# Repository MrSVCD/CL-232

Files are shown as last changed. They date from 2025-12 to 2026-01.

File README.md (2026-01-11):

# CL-232

## In progress - Ver 0.4

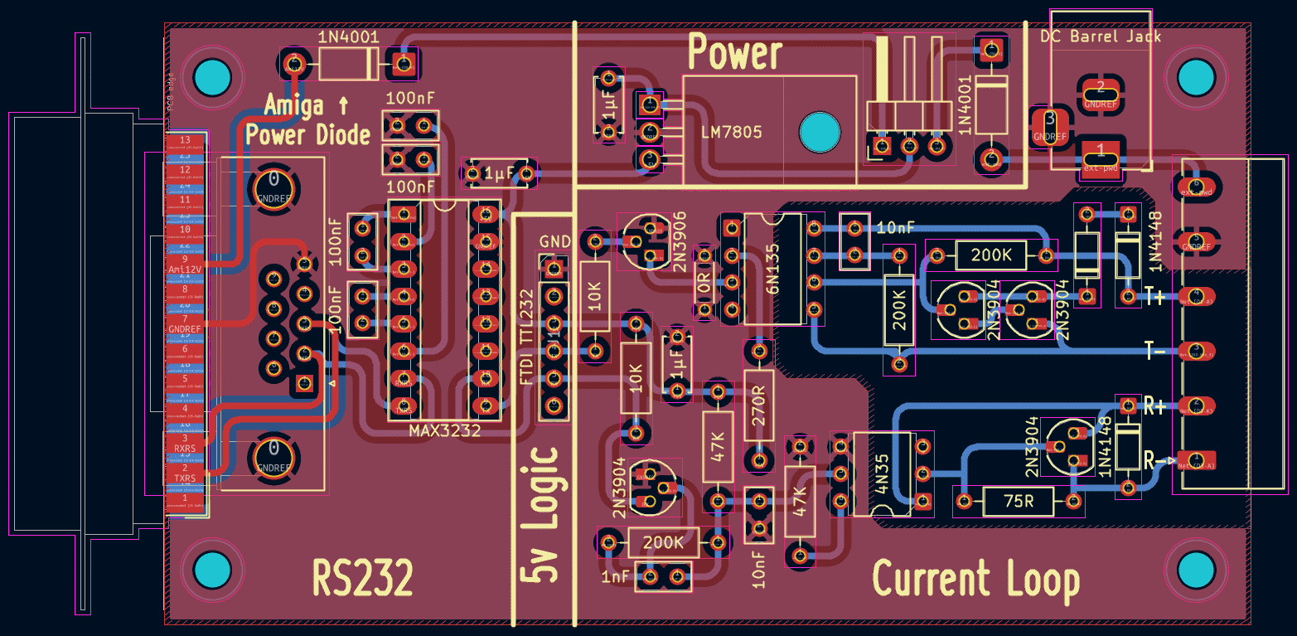
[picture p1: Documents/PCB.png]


This is a current loop to 5V Logic/RS232 adapter for using old old hardware or serial communication over a long distance, old old school style.

The adapter is based on B&B electronics [design](Documents/B&B%20Electronics%20-%20232CL9R.pdf) with some additions sutch as running of a Amiga serial ports power or skipping the whole RS232 to 5V Logic converter part and run it of a USB to TTL232 adapter. 

I also changed the 5V Logic <-> RS232 chip to a single MAX3232 which has the added benefit to only need +5v instead of the old design needing +/-12v, this also makes the adapter able to run on USB power. The Current Loop probably needs more than 5v to get any length going but it should be possible to get a short link going with just 5v, all the old documentation I have found uses 12v or more. 

## Current Limiter
In the folder [CurrentLimiter](CurrentLimiter) there is a simple Current Limiter based on a LM317 and a 62Ω resistor. This current limiter works on a loop up to 40 volts.

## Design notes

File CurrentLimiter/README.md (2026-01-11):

# Current Limiter
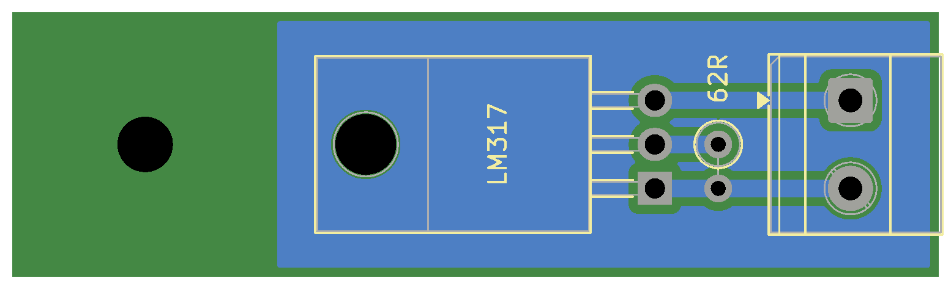
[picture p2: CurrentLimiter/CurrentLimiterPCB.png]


This is a simple PCB that uses a LM317 and a 68Ω resistor to make a 20mA current limiter that adjusts for different voltages (up to 40volts).

The circuit is so simple that a PCB is not really necessary. If you build one without a PCB, remember that the exposed metal on the TO-220 version is connected to voltage out and should be isolated if it needs cooling.

## Resistor value examples:
| Target mA | Exact Ω | Nearest E24 resistor| Resulting mA |
|---:|---:|---:|---:|
| 5 |  256,00 | 270 | 4,74 |
| 10 |  128,00 | 120 | 10,67 |
| 20 | 64,00 | 62 | 20,65 |
| 30 | 42,67 | 43 | 29,77 |
| 40 | 32,00 | 33 | 38,79 |
| 50 | 25,60 | 27 | 47,41 |

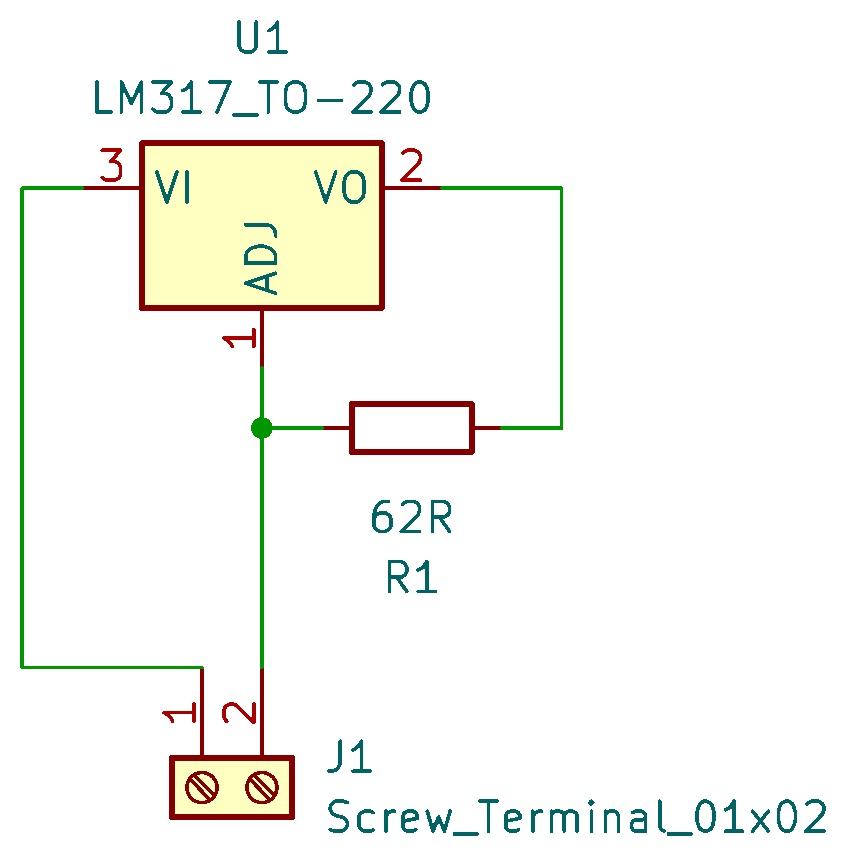
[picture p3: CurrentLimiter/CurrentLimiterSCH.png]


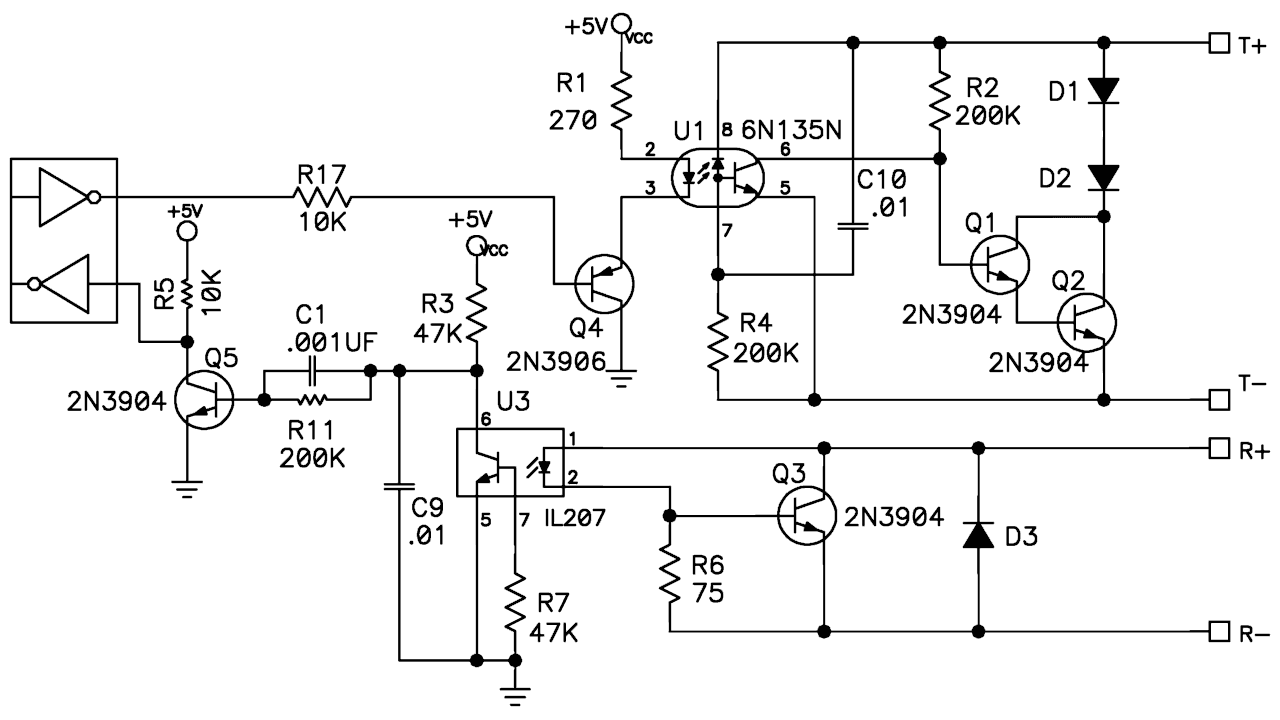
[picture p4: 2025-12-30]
Documents/B&B Electronics - 232CL9R - Schematic.png

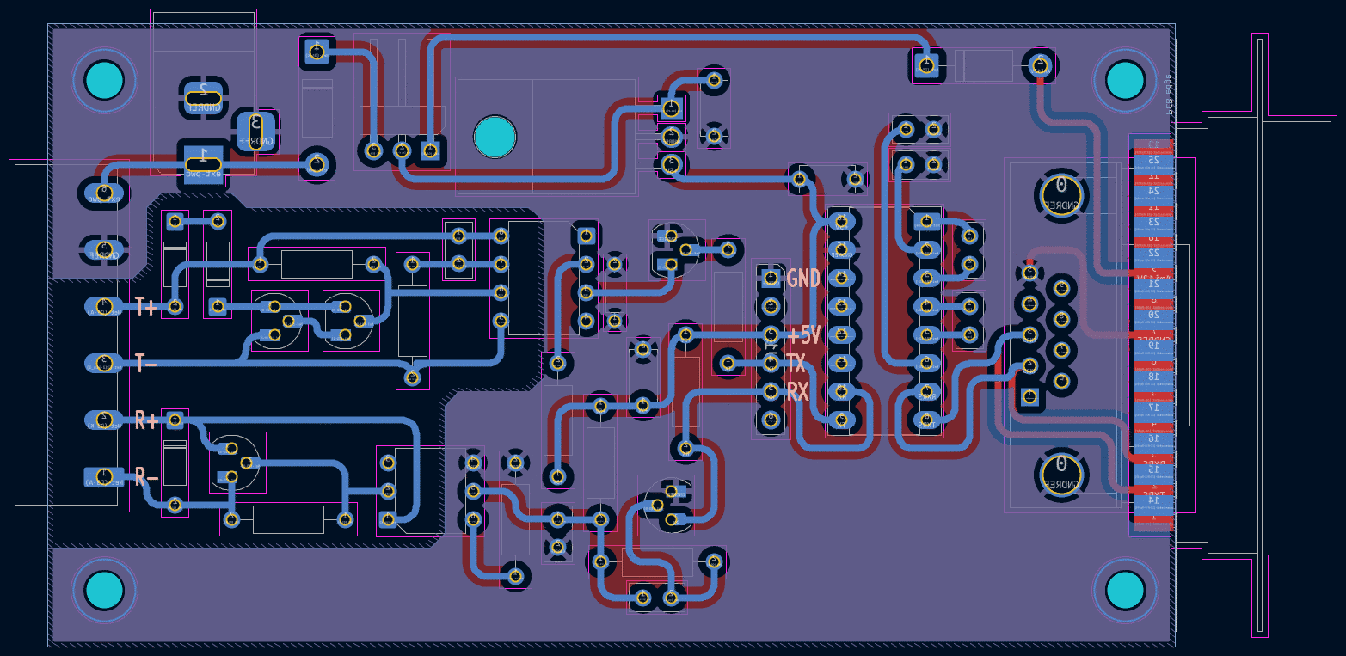
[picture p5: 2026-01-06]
Documents/PCB-back.png

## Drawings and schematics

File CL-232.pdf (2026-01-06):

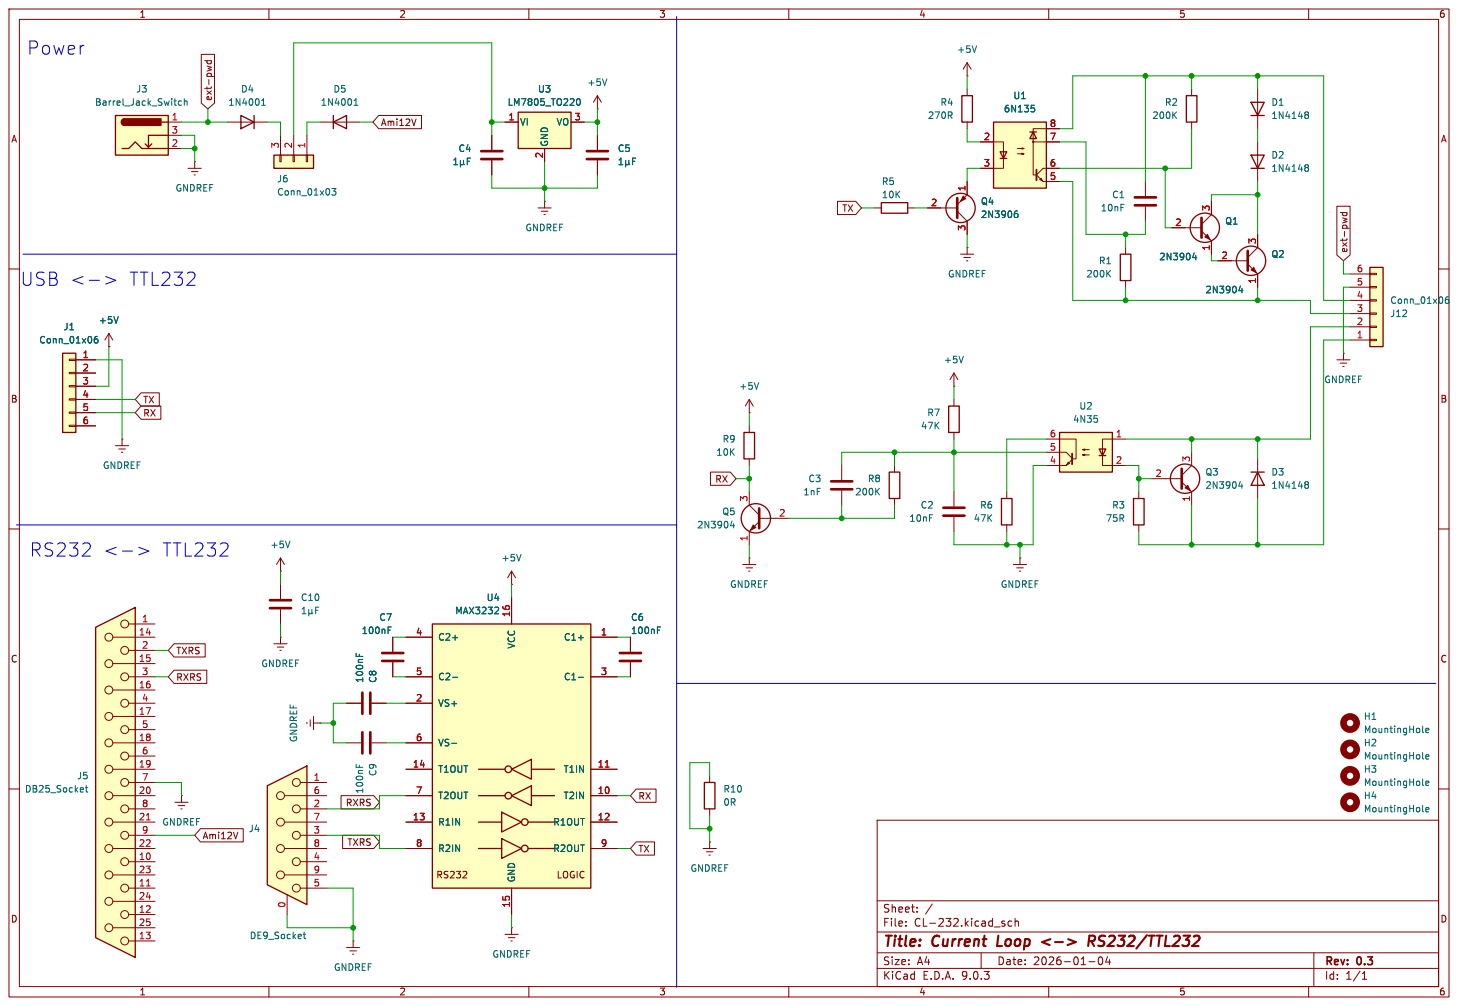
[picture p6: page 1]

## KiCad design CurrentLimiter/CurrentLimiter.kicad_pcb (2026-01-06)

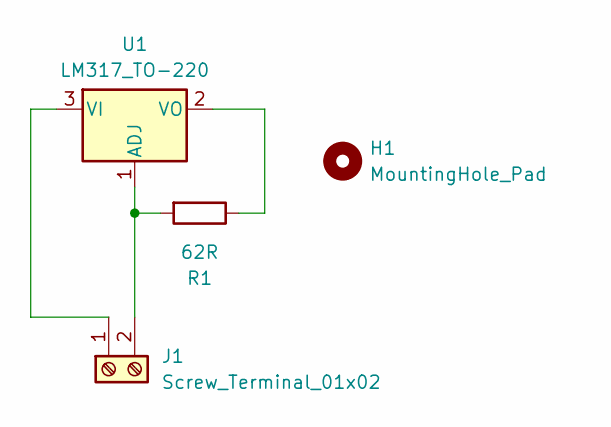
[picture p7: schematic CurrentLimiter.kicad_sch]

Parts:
H1: MountingHole_Pad; MountingHole_3.2mm_M3
J1: Screw_Terminal_01x02; TerminalBlock_Phoenix_MKDS-1,5-2-5.08_1x02_P5.08mm_Horizont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
R1: 62R; R_Axial_DIN0207_L6.3mm_D2.5mm_P2.54mm_Vertical
U1: LM317_TO-220; TO-220-3_Horizontal_TabDown

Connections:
unnamed: J1.1, U1.3 (VI)
unnamed: J1.2, R1.2, U1.1 (ADJ)
unnamed: R1.1, U1.2 (VO)

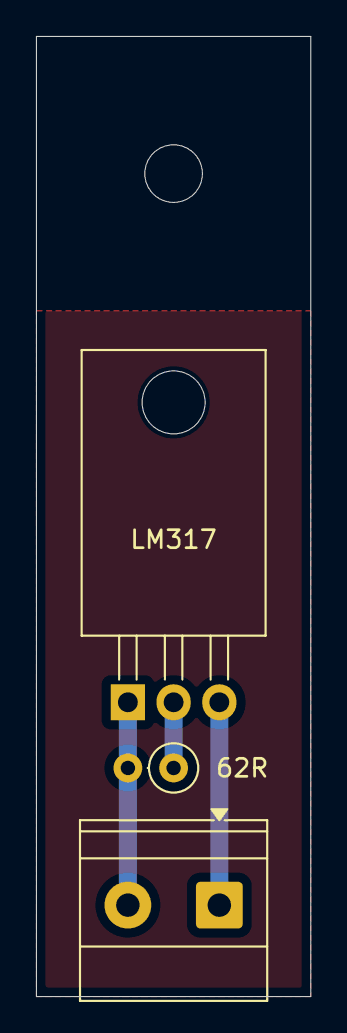
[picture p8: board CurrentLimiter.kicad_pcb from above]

Board: 2 copper layers, 15.2 x 53.3 mm, 4 parts (0 on the bottom side), 3 nets.

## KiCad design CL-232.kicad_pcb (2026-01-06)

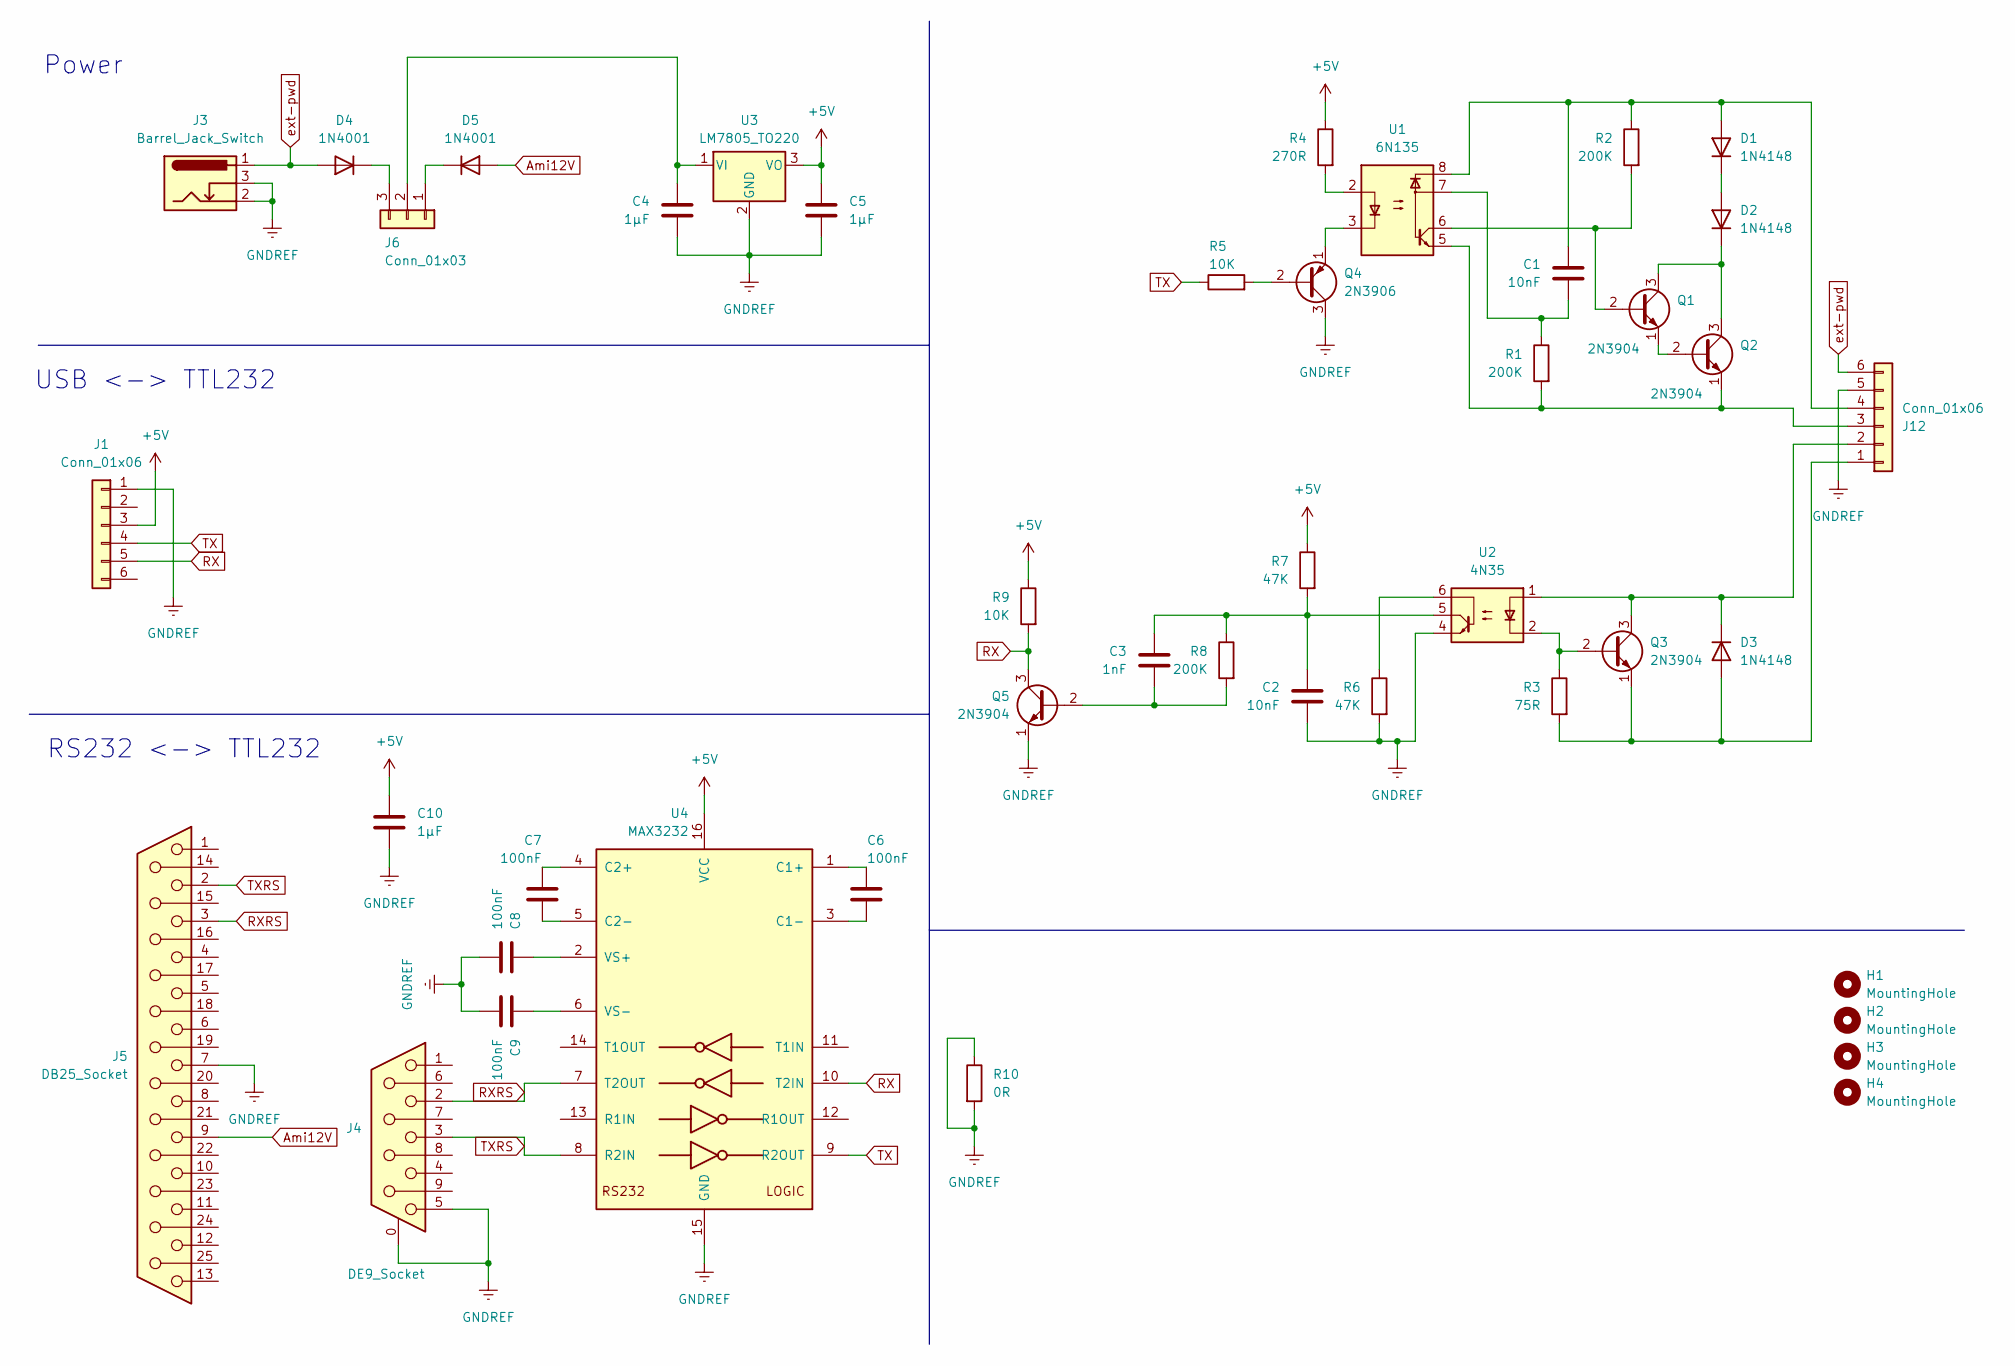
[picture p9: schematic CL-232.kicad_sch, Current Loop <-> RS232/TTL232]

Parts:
C1, C2: 10nF; C_Disc_D5.0mm_W2.5mm_P2.50mm
C3: 1nF; C_Disc_D5.0mm_W2.5mm_P2.50mm
C4, C5, C10: 1µF; C_Disc_D5.0mm_W2.5mm_P5.00mm
C6, C7, C8, C9: 100nF; C_Disc_D5.0mm_W2.5mm_P2.50mm
D1, D2, D3: 1N4148; D_DO-35_SOD27_P7.62mm_Horizontal
D4, D5: 1N4001; D_DO-41_SOD81_P10.16mm_Horizontal
H1, H2, H3, H4: MountingHole; MountingHole_3.2mm_M3_ISO14580
J1: Conn_01x06; PinHeader_1x06_P2.54mm_Vertical
J3: Barrel_Jack_Switch; BarrelJack_Horizontal
J4: DE9_Socket; DSUB-9_Socket_Horizontal_P2.77x2.84mm_EdgePinOffset4.94mm_H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
J5: DB25_Socket; DSUB-25_Socket_EdgeMount_P2.77mm
J6: Conn_01x03; PinHeader_1x03_P2.54mm_Horizontal
J12: Conn_01x06; PhoenixContact_MC_1,5_6-G-5.08_1x06_P5.08mm_Horizontal
Q1, Q2: 2N3904; TO-92L_HandSolder
Q3, Q5: 2N3904; TO-92_HandSolder
Q4: 2N3906; TO-92L_HandSolder
R1, R2, R8: 200K; R_Axial_DIN0207_L6.3mm_D2.5mm_P10.16mm_Horizontal
R3: 75R; R_Axial_DIN0207_L6.3mm_D2.5mm_P10.16mm_Horizontal
R4: 270R; R_Axial_DIN0207_L6.3mm_D2.5mm_P10.16mm_Horizontal
R5, R9: 10K; R_Axial_DIN0207_L6.3mm_D2.5mm_P10.16mm_Horizontal
R6, R7: 47K; R_Axial_DIN0207_L6.3mm_D2.5mm_P10.16mm_Horizontal
R10: 0R; R_Axial_DIN0204_L3.6mm_D1.6mm_P5.08mm_Horizontal
U1: 6N135; DIP-8_W7.62mm
U2: 4N35; DIP-6_W7.62mm
U3: LM7805_TO220; TO-220F-3_Horizontal_TabDown
U4: MAX3232; DIP-16_W7.62mm_Socket_LongPads

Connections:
+5V: C5.1, C10.1, J1.3, R4.1, R7.1, R9.1, U3.3 (VO), U4.16 (VCC)
Ami12V: D5.2 (A), J5.9
GNDREF: C2.2, C4.2, C5.2, C8.2, C9.2, C10.2, J1.1, J3.2, J3.3, J4.0 (PAD), J4.5, J5.7, J12.5, Q4.3 (C), Q5.1 (E), R6.2, R10.1, R10.2, U2.4, U3.2 (GND), U4.15 (GND)
unnamed: C1.2, R1.1, U1.7
unnamed: C2.1, C3.1, R7.2, R8.1, U2.5
unnamed: C1.1, D1.2 (A), J12.4, R2.1, U1.8
unnamed: D1.1 (K), D2.2 (A)
unnamed: D2.1 (K), Q1.3 (C), Q2.3 (C)
unnamed: D3.2 (A), J12.1, Q3.1 (E), R3.2
unnamed: D3.1 (K), J12.2, Q3.3 (C), U2.1
unnamed: D4.1 (K), J6.3
unnamed: D5.1 (K), J6.1
unnamed: C4.1, J6.2, U3.1 (VI)
unnamed: J12.3, Q2.1 (E), R1.2, U1.5
unnamed: Q1.2 (B), R2.2, U1.6
unnamed: Q1.1 (E), Q2.2 (B)
unnamed: Q3.2 (B), R3.1, U2.2
unnamed: Q4.2 (B), R5.2
unnamed: Q4.1 (E), U1.3
unnamed: C3.2, Q5.2 (B), R8.2
unnamed: R4.2, U1.2
unnamed: R6.1, U2.6
unnamed: C6.1, U4.1 (C1+)
unnamed: C6.2, U4.3 (C1-)
unnamed: C7.1, U4.4 (C2+)
unnamed: C7.2, U4.5 (C2-)
unnamed: C8.1, U4.2 (VS+)
unnamed: C9.1, U4.6 (VS-)
RX: J1.5, Q5.3 (C), R9.2, U4.10 (T2IN)
RXRS: J4.2, J5.3, U4.7 (T2OUT)
TX: J1.4, R5.1, U4.9 (R2OUT)
TXRS: J4.3, J5.2, U4.8 (R2IN)
ext-pwd: D4.2 (A), J3.1, J12.6

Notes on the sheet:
Power
RS232 <-> TTL232
USB <-> TTL232

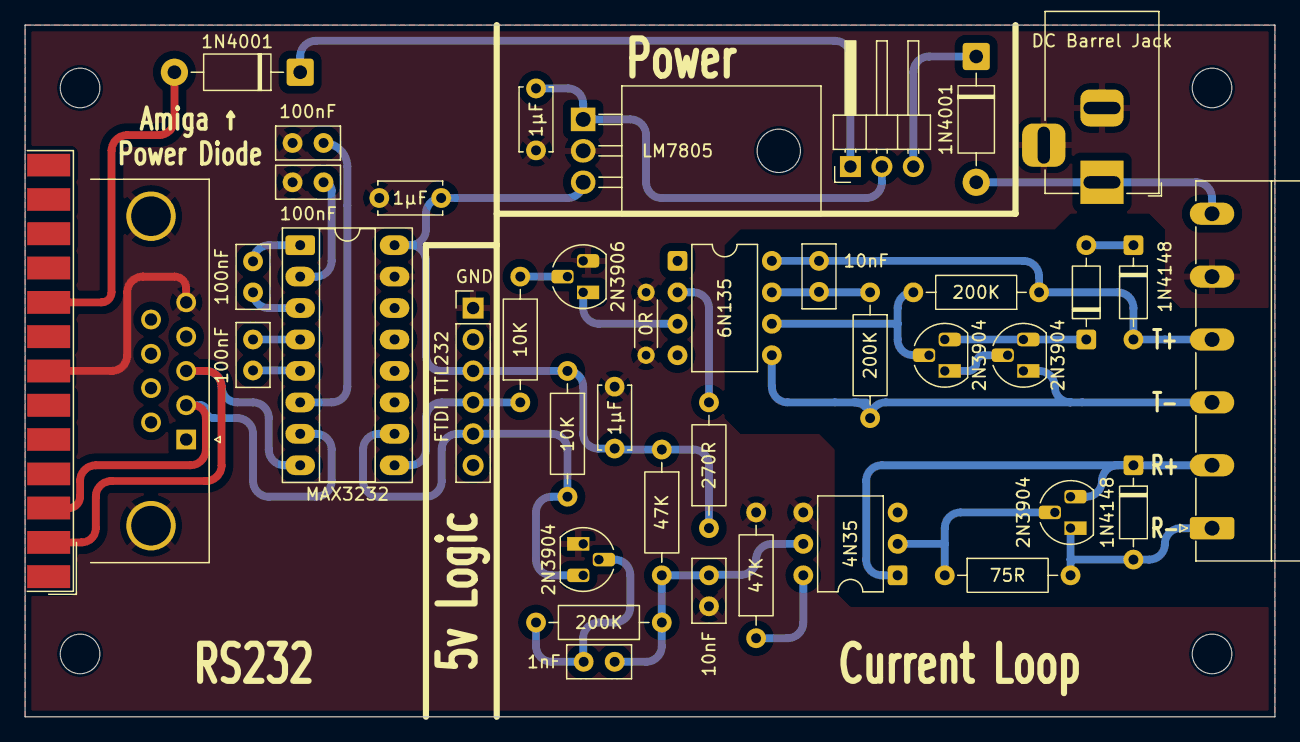
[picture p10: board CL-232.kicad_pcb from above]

Board: 2 copper layers, 101.0 x 55.9 mm, 44 parts (0 on the bottom side), 33 nets.

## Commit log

2025-12-30 Upload files to "/"
    [CL-232.kicad_pcb, CL-232.kicad_sch]
2025-12-30 2025-12-30 21:43
    [CL-232.kicad_pcb, CL-232.kicad_sch]
2025-12-31 First Draft
    [CL-232.kicad_pcb, CL-232.kicad_sch]
2025-12-31 First revision is done.
    [CL-232.kicad_pcb, CL-232.kicad_sch]
2025-12-31 More slime line
    [CL-232.kicad_pcb]
2026-01-01 Version 0.2
    [CL-232.kicad_pcb, CL-232.kicad_sch]
2026-01-01 Version 0.2.1
    [CL-232.kicad_pcb]
2026-01-03 CurrentLimiter added
    [CurrentLimiter.kicad_pcb, CurrentLimiter.kicad_sch]
2026-01-04 Version 0.3
    [CL-232.kicad_pcb, CL-232.kicad_sch]
2026-01-05 Version 0.4
    [CL-232.kicad_pcb, CL-232.kicad_sch]
